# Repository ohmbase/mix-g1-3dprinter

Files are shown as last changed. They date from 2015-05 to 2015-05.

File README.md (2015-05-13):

This is the 2nd 3d printer that Ohmbase uses.  We've had it since around late 2013?

The design of Mix G1 is based on Wallace. The main advantage is the mechanical structure, which is easy to understand, build, and does not need much calibration . Mix G1 has one of the smallest nozzle size(0.34mm) that results great printing quality once you have it running. The printing speed can go up to 150mm/s for infill, and the layer hight is as thin as 0.17mm(can't even see the layers). You can check the picture of printed objects at http://blog.mixshop.com/tagged/mix-g1-printing. Download a full archive of parts here: http://file.mixshop.com/forum/upload/g1/Mix%20G1_plastic_parts.zip many seem to be missing below

from http://reprap.org/wiki/Mix_g1

Description 	Mix G1
License 	GPL
Author 	Jing.guo http://reprap.org/wiki/User:Jing.guo
Based-on 	Wallace http://reprap.org/wiki/Wallace 
Categories 	Cartesian-XZ-head 
External Link 	 http://www.mixshop.com/

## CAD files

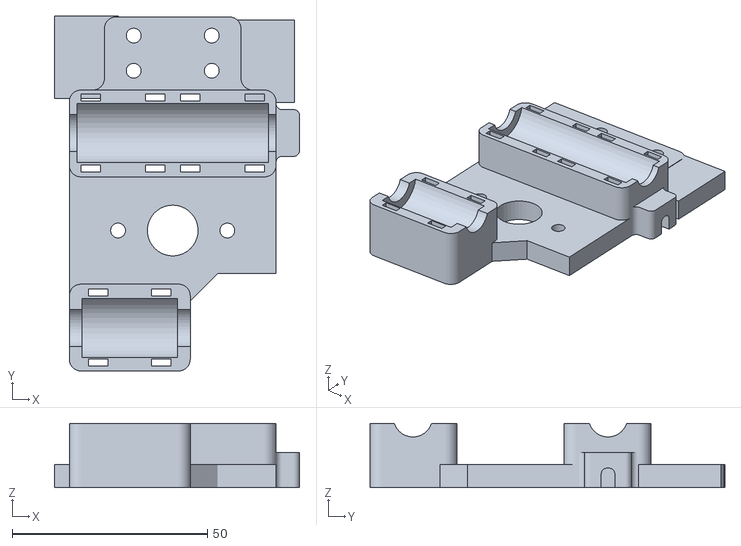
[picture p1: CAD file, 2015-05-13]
base.STL
62.8 x 91.0 x 16.5

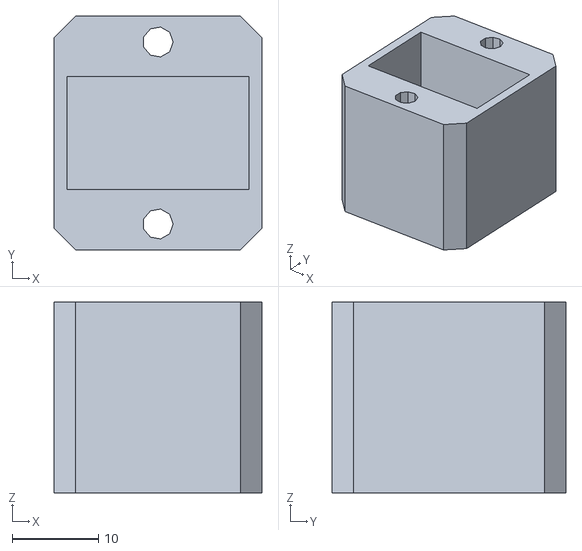
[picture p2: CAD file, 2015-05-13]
power-switch.stl
24.1 x 27.1 x 22.1

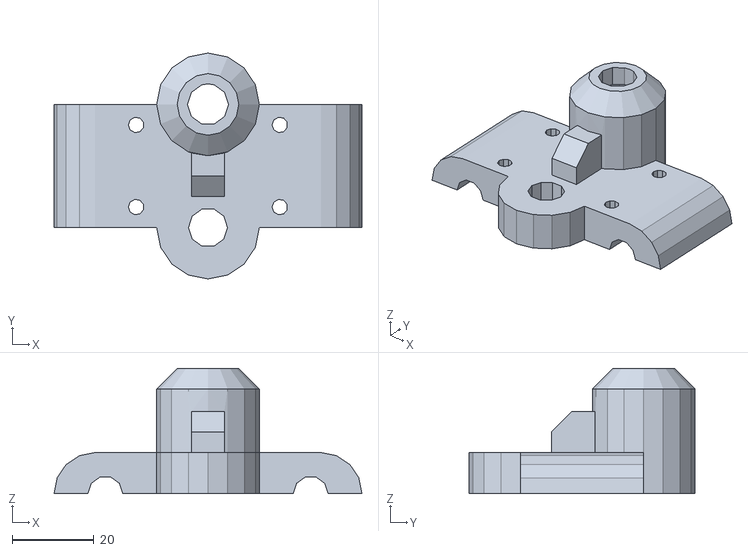
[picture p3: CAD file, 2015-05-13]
x-holder-pp-DIFF.stl
75.3 x 55.2 x 30.6

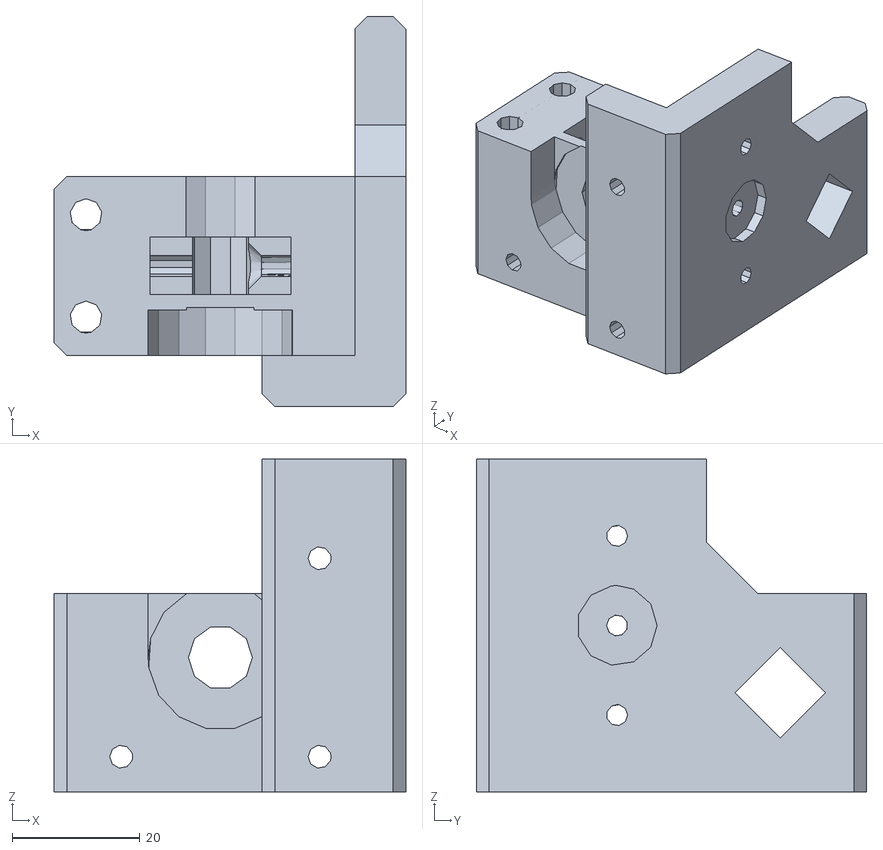
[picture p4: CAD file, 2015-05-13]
extruder_plastic_3.0_pp.stl
55.2 x 61.2 x 52.2

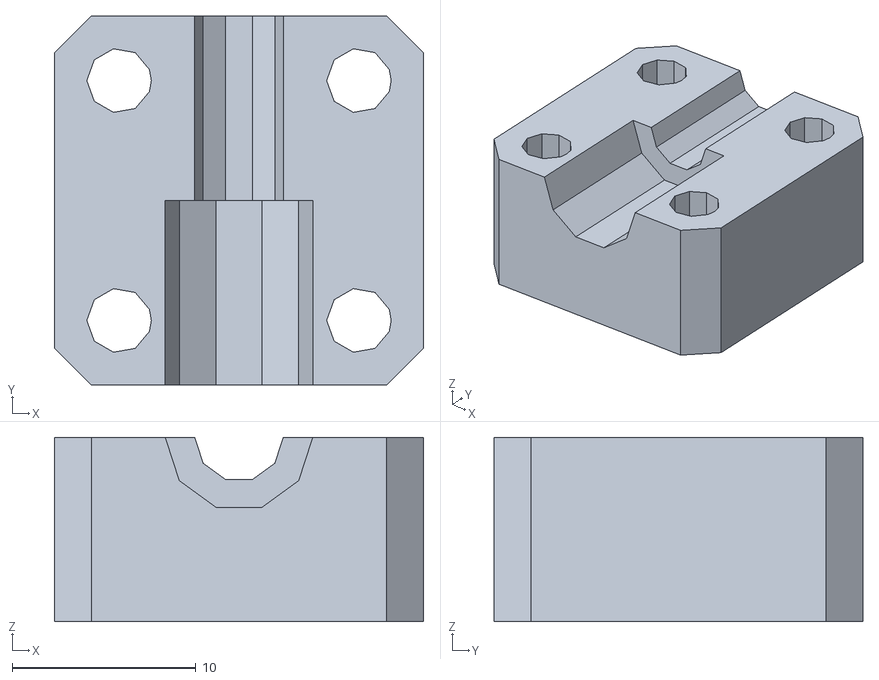
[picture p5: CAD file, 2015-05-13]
z-coupler.stl
20.1 x 20.1 x 10.0

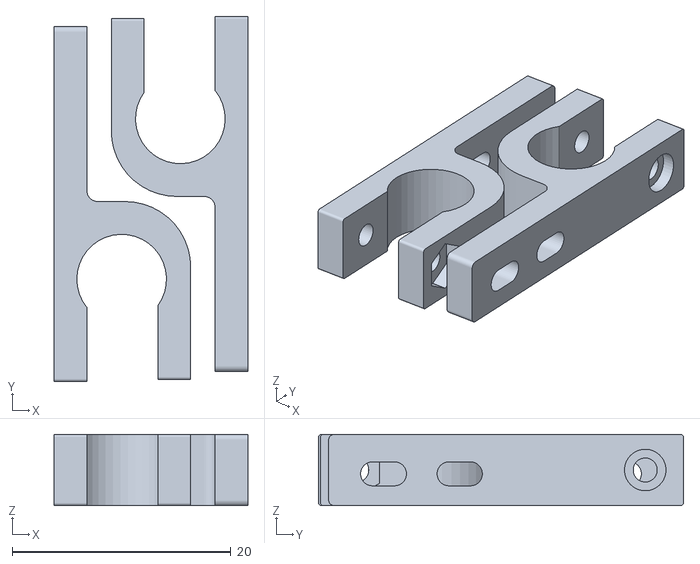
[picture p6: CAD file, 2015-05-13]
small_endstop_holder.STL
17.7 x 33.4 x 6.50

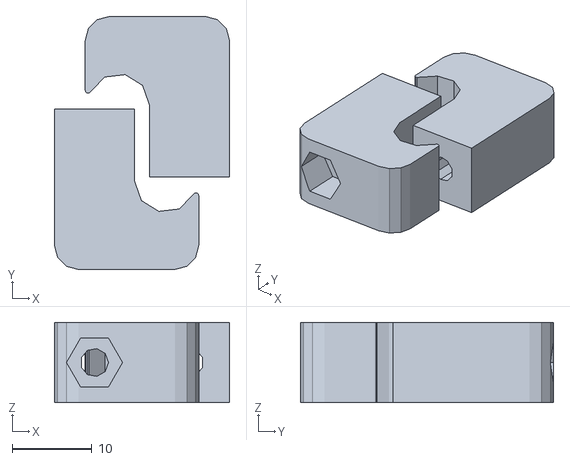
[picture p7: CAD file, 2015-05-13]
base-hook.stl
21.9 x 31.7 x 10.0

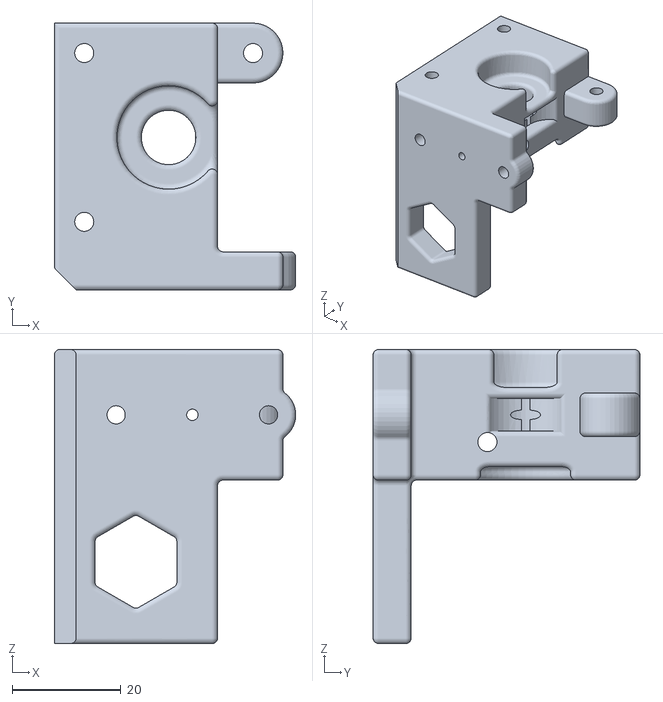
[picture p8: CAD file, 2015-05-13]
Extruder Motor Holder.STL
44.3 x 49.0 x 54.0

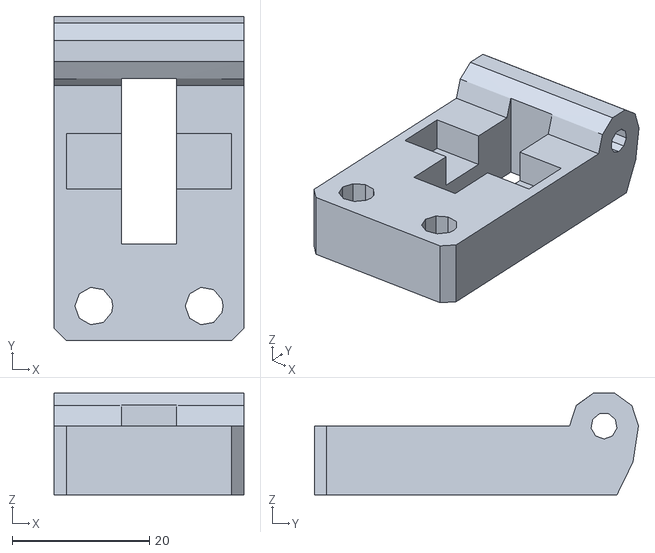
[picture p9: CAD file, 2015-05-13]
extruder_push_pp2.stl
27.6 x 47.2 x 14.8

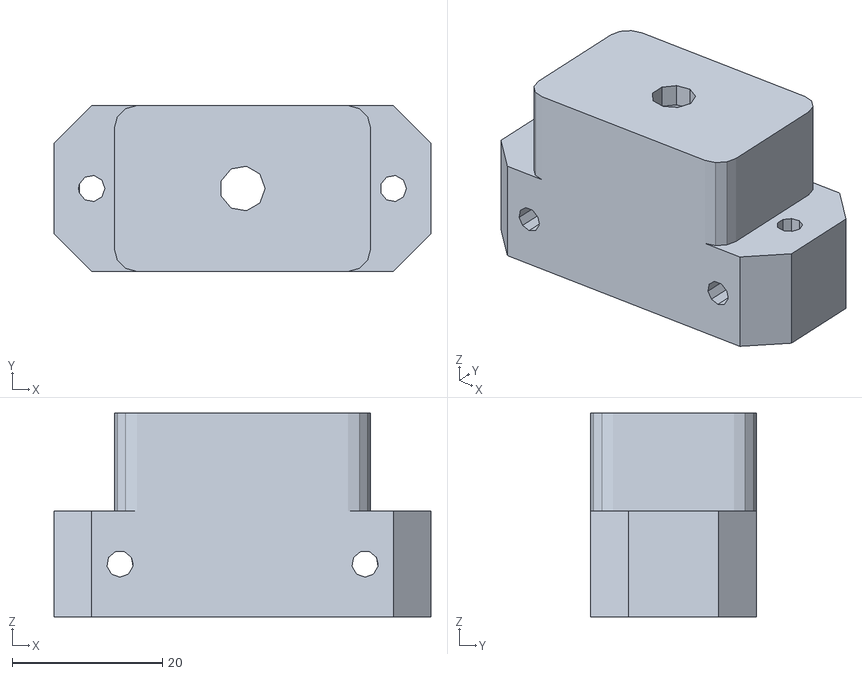
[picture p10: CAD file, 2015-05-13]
power-plug.stl
50.2 x 22.1 x 27.1

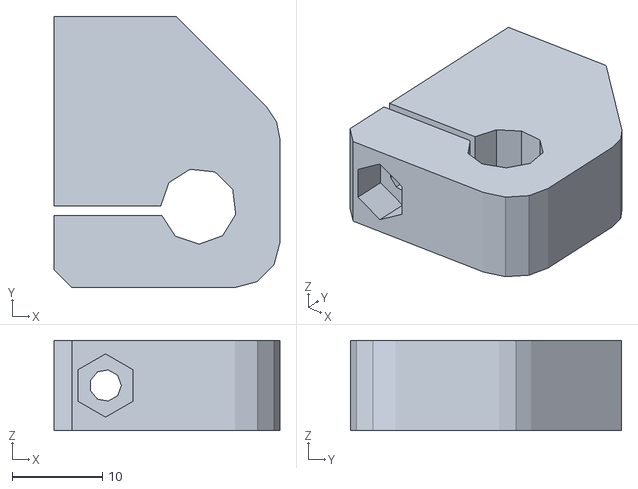
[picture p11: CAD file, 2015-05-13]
plate_base_1_pp-DIFF.stl
25.1 x 30.1 x 10.0

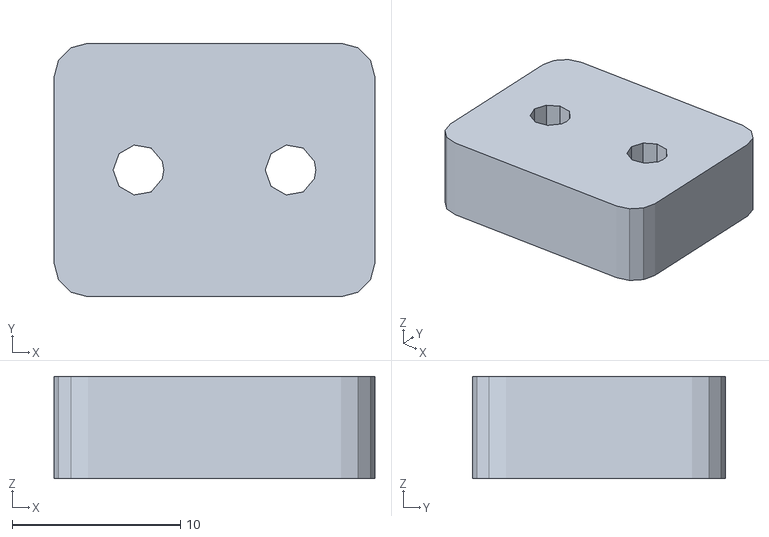
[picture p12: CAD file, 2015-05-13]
bar-clamp.stl
19.1 x 15.1 x 6.08

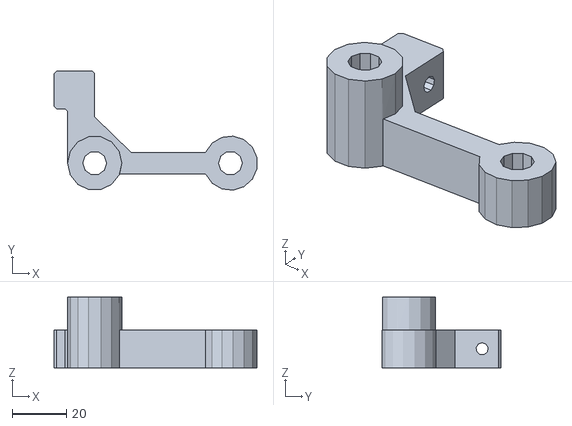
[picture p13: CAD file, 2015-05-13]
x-motor-holder-4_pp.stl
75.1 x 44.1 x 26.1

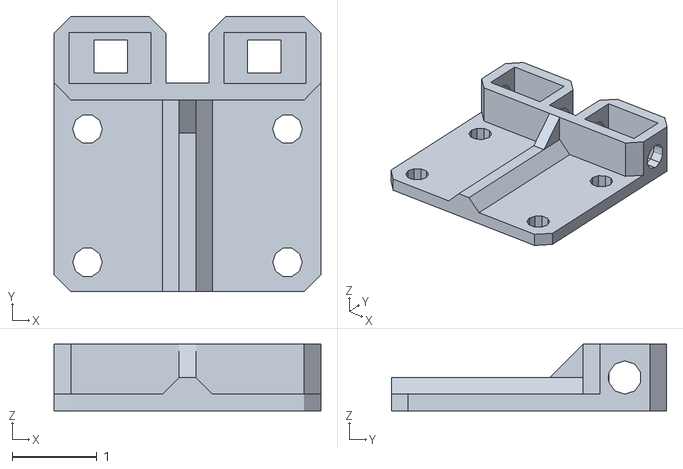
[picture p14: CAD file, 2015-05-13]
base_part_2_pp.stl
3.15 x 3.25 x 0.787

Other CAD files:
z-holder.stl
base-top-2_pp.stl
y-motor-holder_pp.stl
power-supply-hook-pp.stl
base_part_1_pp.stl
plate_base_1_pp.stl
pulley.stl
x-motor-holder-2-pp.stl

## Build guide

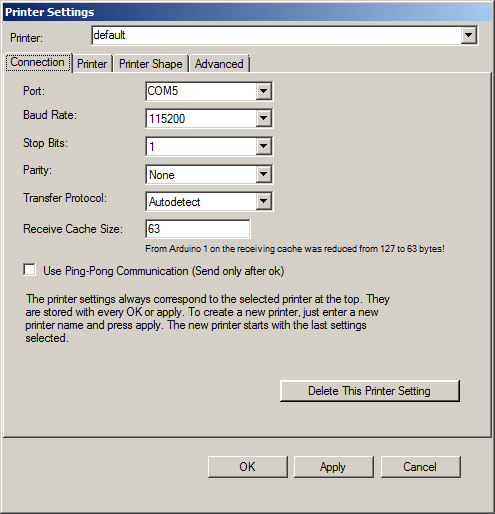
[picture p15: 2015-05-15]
config/Printer_Settings_Connection.png

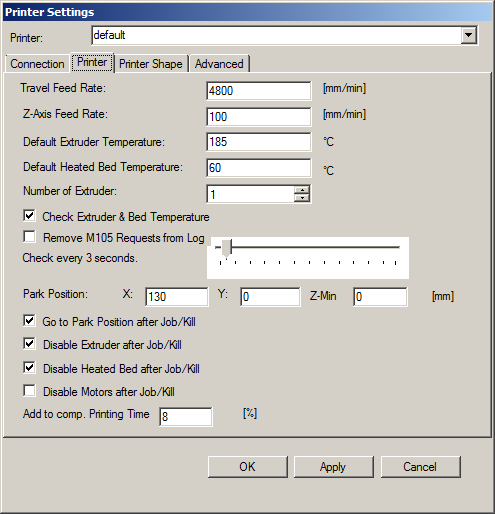
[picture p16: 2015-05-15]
config/Printer_Settings_Printer.png

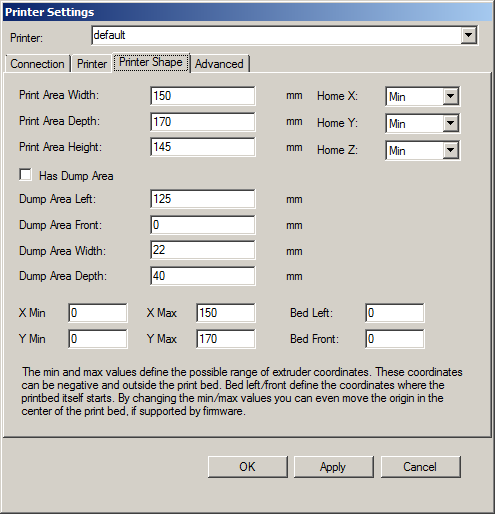
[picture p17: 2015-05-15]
config/Printer_Settings_Printer_Shape.png

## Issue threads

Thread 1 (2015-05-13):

Extruder overflows back into filament chamber

themusicgod1, 2015-05-13:
This is possibly not a problem with the design,  needs investigation.

themusicgod1, 2015-05-15:
seems like cooling issue: fan MUST be pointed at extruder

themusicgod1, 2015-05-15:
this might be resolved now.

themusicgod1, 2015-05-26:
I'd say this is resolved.

Closed 2015-05-26.

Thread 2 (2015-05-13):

piece that connects to x axis bar on extruder piece snapped top.

themusicgod1, 2015-05-13:
needs reinforcement.

themusicgod1, 2015-05-14:
Reinforcement printed and committed.

Closed 2015-05-14.

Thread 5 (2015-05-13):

put repetier/slic3r settings here

themusicgod1, 2015-05-13:
so that in case that machine gets replaced or dropped off of the roof of the library we have a backup.

themusicgod1, 2015-05-15:
old settings uploaded

themusicgod1, 2015-05-15:
new settings here, this is resolved.

Closed 2015-05-15.

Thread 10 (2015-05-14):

belt sitting too low

themusicgod1, 2015-05-14:
belt side of base.STL is too low, belt ends up with a bow in it.

alternatively, it's too high: the belt rubs against wooden attachemnets

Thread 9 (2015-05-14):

middle washer wrong size for top extruder piece

themusicgod1, 2015-05-14:
Make washer size smaller or washer indent larger.

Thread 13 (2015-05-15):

Occasionally extruder leaves printing area

themusicgod1, 2015-05-15:
It is printing just fine, then suddenly goes well the hell out in the direction where there is no endstops.

1) verify slic3r isn't breaking (short term)
2) put end stops on( longer term)

themusicgod1, 2015-05-26:
this seems to be when one of the cables on the x or y axis end stop gets disconnected.

themusicgod1, 2015-06-24:
that's what it was

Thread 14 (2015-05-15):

Screw cracks plastic on piece of extruder that holds the piece that holds the wheel

themusicgod1, 2015-05-15:
1) figure out which object this is fo
2) increase width of wall
3) try printing at different angle

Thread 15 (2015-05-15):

fan just hanging

themusicgod1, 2015-05-15:
should probably make the fan a little more stable

themusicgod1, 2015-10-01:
This causes problem: overheating of arduino, which causes the base to not heat up.  This is critical

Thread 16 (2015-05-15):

blobs

themusicgod1, 2015-05-15:
Getting blobs forming on long prints

themusicgod1, 2015-06-09:
hypothesis: extruder not screwed in sufficiently and plastic is coming out the top.
solution: screw in extruder tighter. (must be hot to do so)

themusicgod1, 2015-06-24:
seems to be what it was.

Closed 2015-06-27.

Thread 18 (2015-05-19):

bottom 4 screws tying actual printer to base should be larger, plastic parts bigger to provide more angular stability

themusicgod1, 2015-05-19:
nt

themusicgod1, 2015-05-22:
chrisr suggests triangular piece on the motor side of the y axis motor near the base

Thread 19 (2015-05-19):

Extruder Motor Holder pit too thin

themusicgod1, 2015-05-19:
with the hex hole pointing down and the opening to the "C" pointing left, the dip in the the wall ends up being too thin -- the wall doesn't print quite so well but really it's too thin.

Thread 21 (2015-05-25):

base_part_1_pp too small

themusicgod1, 2015-05-25:
it is tiny

themusicgod1, 2015-05-25:
base_part_1_pp.stl
base_part_2_pp.stl

both seem way too small even at 1000%.  Will measure

themusicgod1, 2015-05-25:
2666% scale might work

themusicgod1, 2015-05-25:
17.1 cm at 2666% and it's too big. should be 16.7 ...try 2603%

themusicgod1, 2015-05-28:
in addition to the whole thing being wrong, the y axis is scaled wrong.
It is 14.3 cm at the top, should be 13.5 cm for total of

26.03
24.57
26.03

themusicgod1, 2015-05-29:
base_part_2 is 14mm on x axis at the top, to the 13.5 mm for base_part_1.  This is incorrect, somewhere

themusicgod1, 2015-06-25:
Base part 2 is still wrong, ugh.  Should be SHORTER along x axis.

base_part_1
24.57 (was 78.99+/-.16mm should be 79.86mm)  ->
25.82 (was 62.29+/-.31mm is probably OK)         ->
26.03 (was 4.9+/-.01mm should be 5.25mm)       ->

base_part_2
25.86 (was 81.86mm should be 79.53)                ->
25.26 (was 82.19mm is probably OK)                 ->
26.03 (was 20.54mm should be 20.0)                  ->

themusicgod1, 2015-07-06:
I'm starting to think that last z correction on base_part_1 was wrong

base_part_1
24.84
25.82
26.03

base_part_2

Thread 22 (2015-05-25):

endstop_holder is too big

themusicgod1, 2015-05-25:
easily 3x too big

themusicgod1, 2015-05-25:
prints 10cm  needs to be ~6.66.   so 2/3 scale needed.

themusicgod1, 2015-05-26:
was not the right end stop for this project, removed

Closed 2015-05-26.

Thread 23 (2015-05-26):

y pulley broken

themusicgod1, 2015-05-26:
reprint, reattach.  While we're at it, screw in the base screws to prevent the whole thing from wobbling.

themusicgod1, 2015-05-28:
fixz0r3d

Closed 2015-05-28.

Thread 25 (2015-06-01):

LM8UU on y and z axis

themusicgod1, 2015-06-01:
Linear bearing unit, as per x axis, should be on all axis.  This is a possible precondition for wider surface area in case we run into constraints.

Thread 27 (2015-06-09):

extruder pusher there's 2 stls

themusicgod1, 2015-06-09:
pick one

themusicgod1, 2015-06-16:
"extruder pusher" is wrong

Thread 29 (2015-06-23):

x-holder-pp is too big in the long side

themusicgod1, 2015-06-23:
it is 76.92 mm
it should be
69.33 mm

themusicgod1, 2015-06-24:
this is along x axis.  Scale 0.9013

themusicgod1, 2015-06-24:
may be printer setting issue: size wasn't correct for y and x axis

themusicgod1, 2015-06-24:
looks like it's still wrong

themusicgod1, 2015-07-02:
actually it looks like it was right all along

themusicgod1, 2015-07-02:
(it's nothing at all like the original piece but it seems to work)

themusicgod1, 2015-07-30:
this was a valid bug

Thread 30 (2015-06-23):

bar-clamp snapped in half

themusicgod1, 2015-06-23:
in between the two screws

maybe make them wider?

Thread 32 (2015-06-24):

one side of shading is separating from walls

themusicgod1, 2015-06-24:
chris' hypothesis: y belt not tight enough.

themusicgod1, 2015-06-24:
some toying around with the belt system made this a little better, postponing full resolution for abit

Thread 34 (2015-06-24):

bar-clamp.stl needs a nut groove

themusicgod1, 2015-06-24:
it would spread pressure around.
Maybe fork into two things bar-clamp.stl and bar-clamp-with-glued-belt.stl

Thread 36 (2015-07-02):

base-part-1 part that grips stepper motor not thick enough

themusicgod1, 2015-07-02:
redesign add some thickness

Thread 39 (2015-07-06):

when tightening x axis belt, it's possible to pull bolts together

themusicgod1, 2015-07-06:
bolts cease to be parallel and/or the x-base-tops cease to be far enough apart

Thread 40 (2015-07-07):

nut trap on pulley is too big

themusicgod1, 2015-07-07:
make smaller so nut just fits

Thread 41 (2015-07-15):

x motor should stick out more

themusicgod1, 2015-07-15:
this may mean changes for both the piece that is the motor and the bearing, so that the belt is straighter along the x axis.

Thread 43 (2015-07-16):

x axis slippage

themusicgod1, 2015-07-16:
keep losing x

* could be the belt wearing out
* could be not enough power to the motor
* could be misalignment in design
* could be the bearing
?

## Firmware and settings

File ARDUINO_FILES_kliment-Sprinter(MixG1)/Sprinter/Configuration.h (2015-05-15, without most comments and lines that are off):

#define CONFIGURATION_H
#define MOTHERBOARD 33
#define THERMISTORHEATER 7
#define THERMISTORBED 7
#define _AXIS_STEP_PER_UNIT {80, 80, 3200/1.25,140}
#define ENDSTOPPULLUPS // Comment this out (using // at the start of the line) to disable the endstop pullup resistors
const bool X_ENDSTOP_INVERT = false;
const bool Y_ENDSTOP_INVERT = false;
const bool Z_ENDSTOP_INVERT = false;
#define BAUDRATE 115200
#define USE_ARC_FUNCTION
#define X_ENABLE_ON 0
#define Y_ENABLE_ON 0
#define Z_ENABLE_ON 0
#define E_ENABLE_ON 0
const bool DISABLE_X = false;
const bool DISABLE_Y = false;
const bool DISABLE_Z = true;
const bool DISABLE_E = false;
const bool INVERT_X_DIR = false;
const bool INVERT_Y_DIR = false;
const bool INVERT_Z_DIR = true;
const bool INVERT_E_DIR = false;
#define X_HOME_DIR -1
#define Y_HOME_DIR -1
#define Z_HOME_DIR -1
const bool min_software_endstops = false; //If true, axis won't move to coordinates less than zero.
const bool max_software_endstops = true; //If true, axis won't move to coordinates greater than the defined lengths below.
const int X_MAX_LENGTH = 200;
const int Y_MAX_LENGTH = 200;
const int Z_MAX_LENGTH = 300;
const int NUM_AXIS = 4; // The axis order in all axis related arrays is X, Y, Z, E
#define _MAX_FEEDRATE {400, 400, 4, 45}       // (mm/sec)
#define _HOMING_FEEDRATE {2000,2000,200}      // (mm/min) !!
#define _AXIS_RELATIVE_MODES {false, false, false, false}
#define MAX_STEP_FREQUENCY 30000 // Max step frequency
#define _ACCELERATION 1000         // Axis Normal acceleration mm/s^2
#define _RETRACT_ACCELERATION 2000 // Extruder Normal acceleration mm/s^2
#define _MAX_XY_JERK 20.0
#define _MAX_Z_JERK 0.4
#define _MAX_ACCELERATION_UNITS_PER_SQ_SECOND {5000,5000,50,5000}    // X, Y, Z and E max acceleration in mm/s^2 for printing moves or retracts
#define MINIMUM_PLANNER_SPEED 2.0 // (mm/sec)
#define DEFAULT_MINIMUMFEEDRATE       0.0     // minimum feedrate
#define DEFAULT_MINTRAVELFEEDRATE     0.0
#define SLOWDOWN
const int dropsegments=5; //everything with less than this number of steps will be ignored as move and joined with the next movement
#define _DEF_CHAR_UUID "00000000-0000-0000-0000-000000000000"
  #define BLOCK_BUFFER_SIZE 16
  #define BLOCK_BUFFER_MASK 0x0f
#define MM_PER_ARC_SEGMENT 1
#define N_ARC_CORRECTION 25
#define PIDTEMP 1
#define PID_SOFT_PWM
#define PID_INTEGRAL_DRIVE_MAX 80 // too big, and heater will lag after changing temperature, too small and it might not compensate enough for long-term errors
#define PID_PGAIN 2560 //256 is 1.0  // value of X means that error of 1 degree is changing PWM duty by X, probably no need to go over 25
#define PID_IGAIN 64 //256 is 1.0  // value of X (e.g 0.25) means that each degree error over 1 sec (2 measurements) changes duty cycle by 2X (=0.5) units (verify?)
#define PID_DGAIN 4096 //256 is 1.0  // value of X means that around reached setpoint, each degree change over one measurement (half second) adjusts PWM by X units to compensate
#define HEATER_DUTY_FOR_SETPOINT(setpoint) ((int)((187L*(long)setpoint)>>8)-27)
#define LED_PWM_FOR_BRIGHTNESS(brightness) ((64*brightness-1384)/(300-brightness))
#define HEATER_CURRENT 255
#define HEATER_CHECK_INTERVAL 500
#define BED_CHECK_INTERVAL 5000
#define DISABLE_CHECK_DURING_ACC
#define DISABLE_CHECK_DURING_TRAVEL 1000
#define MINTEMP 5
#define MAXTEMP 275
#define HEATER_USES_THERMISTOR
#define BED_USES_THERMISTOR
#define CONTROLLERFAN_SEC 60 //How many seconds, after all motors were disabled, the fan should run

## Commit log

2015-05-13 adding stl files from http://reprap.org/wiki/Mix_g1
    [base-top-2_pp.stl, base_part_1_pp.stl, base_part_2_pp.stl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]
2015-05-13 missed one- bar clamp
    [bar-clamp.stl]
2015-05-13 Stuff that was in the main "zip" file, incl hopefully the whole printer this time. Apparently it might be version 3?
    [4x base.stl, Extruder Motor Holder.STL, Extruder Pusher.STL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]
2015-05-13 beefier base
    [base.STL]
2015-05-13 better design suggested by ChrisR
    [base.STL]
2015-05-13 real changes, not the last set of changes
    [base.STL]
2015-05-15 added files that were used to setup printer and deleting 4x base
    [4x base.stl, Configuration.h]
2015-05-15 slic3r from AFTER move
    we may already have a slic3r file...in which case it's best to use this as the final resting point but the values from the other one as authoritative
2015-05-22 extra part
    [base-top.stl]
2015-05-25 castle got in here, not sure how that happened
    not related to printer
    [castle-corner.stl]
2015-05-25 Delete endstop-holder.stl
    pretty sure this is for a different printer, use other endstop holder for now.
    [endstop-holder.stl]
2015-06-01 superfluous design
    [small_endstop_holder_set.STL]
2015-06-01 other one seems to compile in repetier better
    [x-holder-pp.stl]
2015-06-16 duplicate
    this is a duplicate and the wrong size to boot
    [Extruder Pusher.STL]
